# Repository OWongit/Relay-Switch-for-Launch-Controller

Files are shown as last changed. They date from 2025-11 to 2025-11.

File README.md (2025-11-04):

# **Relay Switch Board**

## **Overview**
This is a small relay daughterboard for a rocket launch controller. It lets a low-current 5 V GPIO signal safely switch a fused 5 V power line through an opto-isolated relay, while providing clear power and status indication.

---

## **How It Works**
- **GPIO → Optocoupler**: The GPIO pin drives an optocoupler, isolating the controller from the relay coil circuit.
- **Optocoupler → Transistor**: The optocoupler output drives a transistor that switches current through the relay coil.
- **Protection**: A flyback diode protects the transistor from coil transients.
- **Relay Path**: When energized, the relay connects **RelayIn** to **RelayOut** through a fuse.
- **Indicators**: On-board LEDs show when 5 V is present and when the relay/GPIO is active.

---

## Schematic

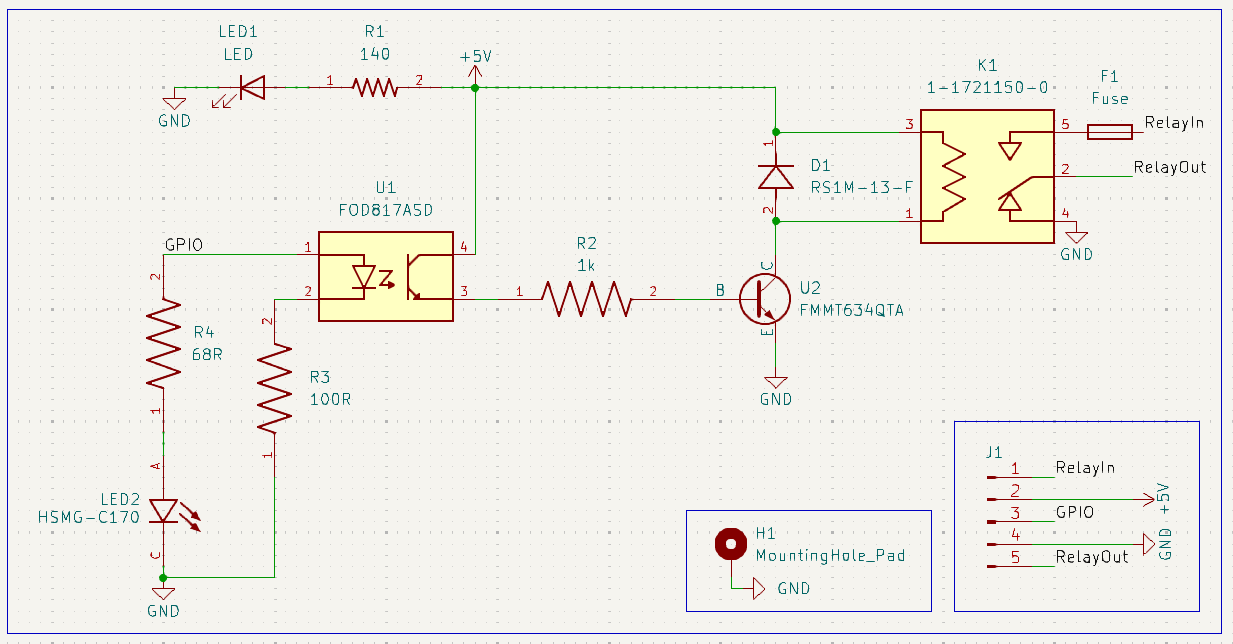
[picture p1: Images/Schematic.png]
Schematic


## PCB Layout

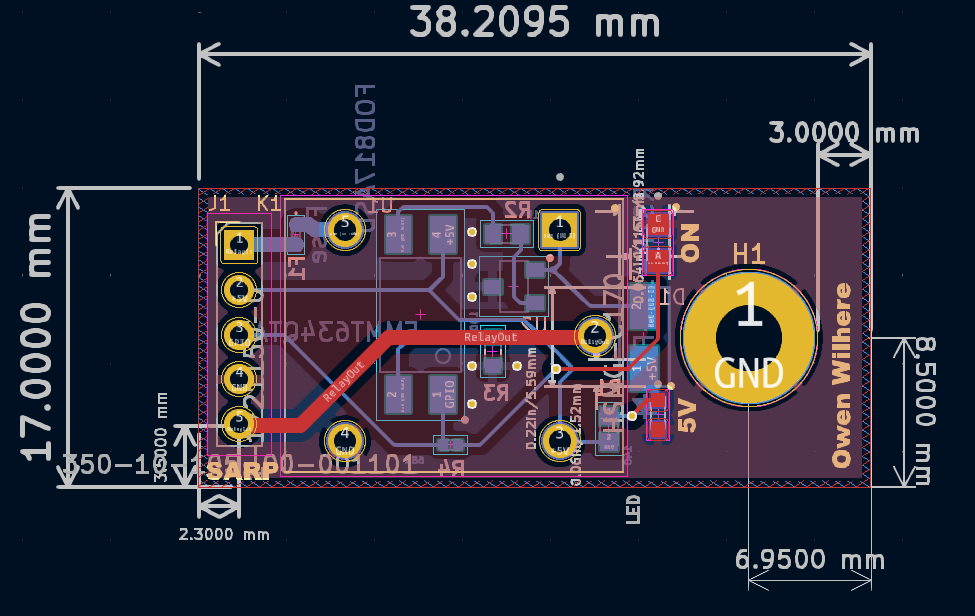
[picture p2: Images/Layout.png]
PCB Layout


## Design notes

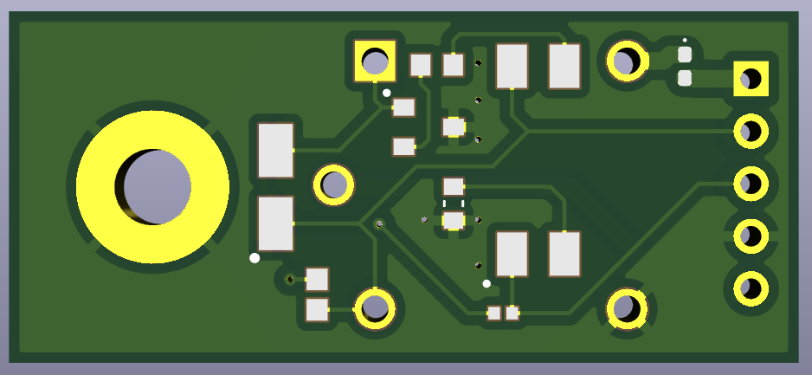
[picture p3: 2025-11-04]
Images/Renderin_Back.png

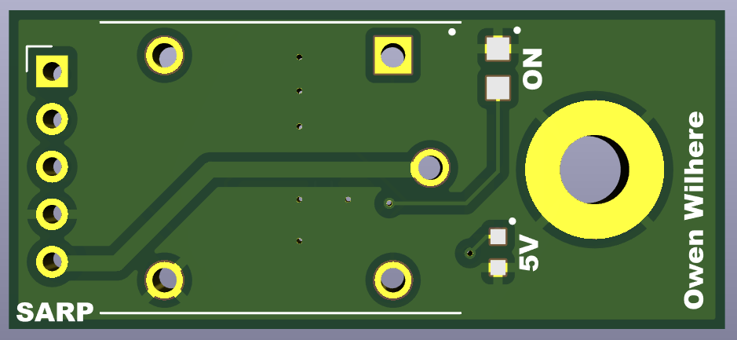
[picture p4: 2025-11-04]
Images/Rendering_Front.png

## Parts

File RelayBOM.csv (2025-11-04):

Reference | Value | Datasheet | Footprint | Qty
D1 | RS1M-13-F | https://www.diodes.com/assets/Datasheets/ds15002.pdf | RS1M-13-F:SMA_DIO-M | 1
F1 | Fuse | https://industrial.panasonic.com/cdbs/www-data/pdf/AFA0000/AFA0000C7.pdf | Diode_SMD:D_0402_1005Metric_Pad0.77x0.64mm_HandSolder | 1
J1 | 350-10-105-00-001101 | https://mm.digikey.com/Volume0/opasdata/d220001/medias/docus/6642/350_Datasheet.pdf | Connector_PinHeader_2.54mm:PinHeader_1x05_P2.54mm_Vertical | 1
K1 | 1-1721150-0 | https://www.te.com/en/product-1-1721150-0.datasheet.pdf | 1-1721150-0:RELAY_1-1721150-0 | 1
LED1 | LED | https://fscdn.rohm.com/en/products/databook/datasheet/opto/led/chip_mono/sml-d12v1wt86-e.pdf | SML-D12:LED_SML-D12V1WT86 | 1
LED2 | HSMG-C170 | https://docs.broadcom.com/doc/AV02-0551EN | HSMG-C170:LED_HSMS-C170 | 1
R1 | 140 | https://www.yageo.com/upload/media/product/products/datasheet/rchip/PYu-RC_Group_51_RoHS_L_12.pdf | RC0603FR-07330RL:RESC1607X60N | 1
R2 | 1k | https://www.susumu.co.jp/common/pdf/n_catalog_partition01_en.pdf | RG1608N-102-D-T5:RESC1608X50N | 1
R3 | 100R | https://www.yageo.com/upload/media/product/productsearch/datasheet/rchip/PYu-AC_51_RoHS_L_11.pdf | AC0603JR-07100RL:RESC1608X55N | 1
R4 | 68R | https://industrial.panasonic.com/cdbs/www-data/pdf/RDA0000/AOA0000C301.pdf | CRCW0402140RFKEDC:RESC1005X35N | 1
U1 | FOD817ASD | https://rocelec.widen.net/view/pdf/yhg4flovvn/ONSM-S-A0003163276-1.pdf?t.download=true&u=5oefqw | FOD817ASD:SOIC254P1016X385-4N | 1
U2 | FMMT634QTA | https://www.diodes.com/assets/Datasheets/FMMT634Q.pdf | FMMT634QTA:VREG_XC6206P282MR-G | 1

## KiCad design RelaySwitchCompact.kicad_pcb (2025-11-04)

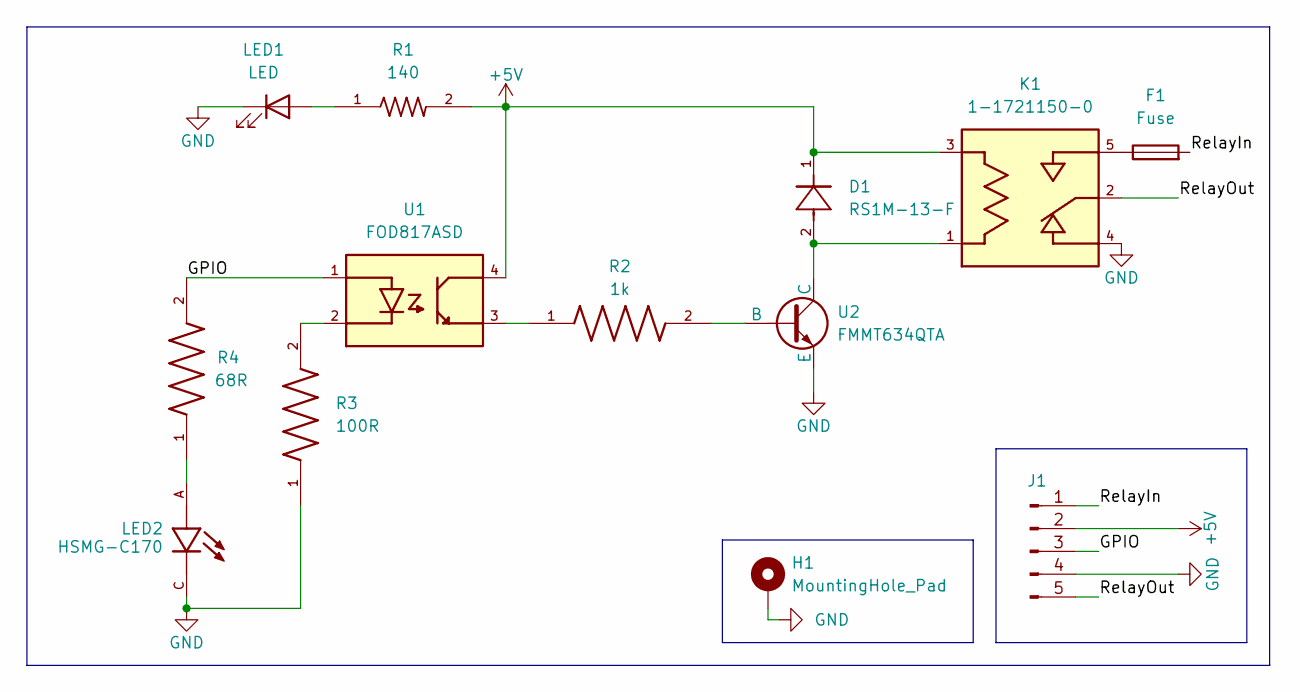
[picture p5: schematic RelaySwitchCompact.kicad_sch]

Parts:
D1: RS1M-13-F; SMA_DIO-M; MANUFACTURER_PART_NUMBER RS1M-13-F
F1: Fuse; D_0402_1005Metric_Pad0.77x0.64mm_HandSolder
H1: MountingHole_Pad; MountingHole_3.7mm_Pad
J1: 350-10-105-00-001101; PinHeader_1x05_P2.54mm_Vertical
K1: 1-1721150-0; RELAY_1-1721150-0; PARTREV D
LED1: LED; LED_SML-D12V1WT86
LED2: HSMG-C170; LED_HSMS-C170; PARTREV March 25, 2022
R1: 140; RESC1607X60N
R2: 1k; RESC1608X50N
R3: 100R; RESC1608X55N
R4: 68R; RESC1005X35N
U1: FOD817ASD; SOIC254P1016X385-4N
U2: FMMT634QTA; VREG_XC6206P282MR-G

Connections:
+5V: D1.1, J1.2, K1.3, R1.2, U1.4
/GPIO: J1.3, R4.2, U1.1
/RelayIn: F1.2, J1.1
/RelayOut: J1.5, K1.2
GND: H1.1, J1.4, K1.4, LED1.1 (K), LED2.C, R3.1, U2.3 (E)
unnamed: F1.1, K1.5
unnamed: LED1.2 (A), R1.1
unnamed: LED2.A, R4.1
unnamed: R2.1, U1.3
unnamed: R3.2, U1.2
unnamed: R2.2, U2.2 (B)
unnamed: D1.2, K1.1, U2.1 (C)

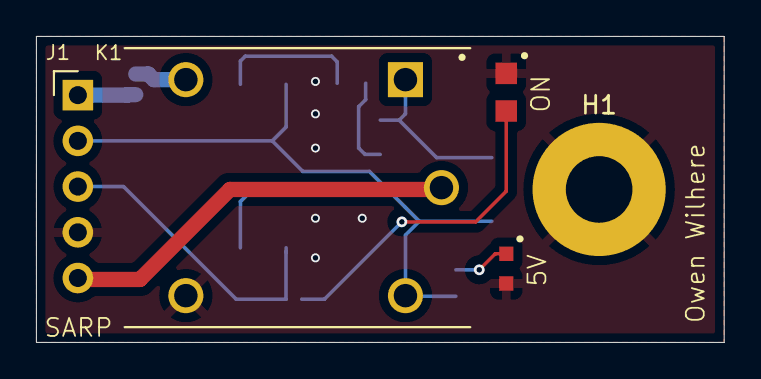
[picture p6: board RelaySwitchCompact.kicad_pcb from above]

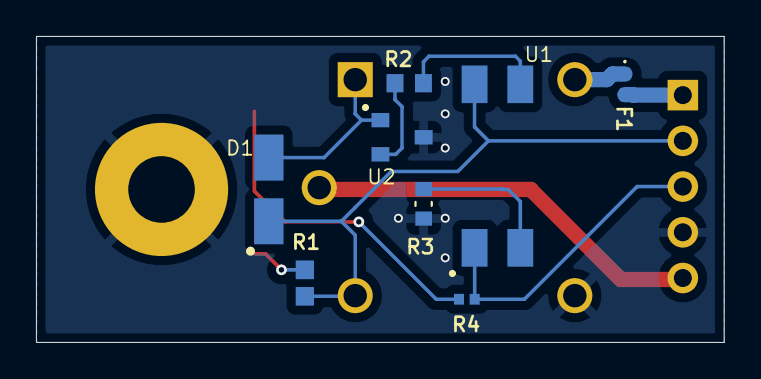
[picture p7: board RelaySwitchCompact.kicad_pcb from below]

Board: 2 copper layers, 38.2 x 17.0 mm, 13 parts (8 on the bottom side), 12 nets.

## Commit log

2025-01-09 files added
    [RelaySwitch.kicad_sch, RelaySwitchCompact.kicad_pcb]
2025-02-20 replaced files
    [RelaySwitchCompact.kicad_pcb]
2025-11-04 updated and cleaned up files.
    [RelayBOM.csv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]

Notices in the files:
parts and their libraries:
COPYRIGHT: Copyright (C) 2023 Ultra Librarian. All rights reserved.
